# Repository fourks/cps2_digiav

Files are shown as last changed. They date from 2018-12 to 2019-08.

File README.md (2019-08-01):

CPS2 digital AV interface (Rev 2 - CPS1 branch)
==============

Features (current)
--------------------------
* framelocked 1080p@59.64Hz output with max. 40 scanline latency
* 24bit/48kHz audio output

TODO
--------------------------
* OSD/UI
* resolution select
* more scanline options
* settings store / profiles

Installation
--------------------------
The add-on board can be installed on top of CPS1 A-board (88617A revisions currently supported). The following additional parts are required:

* cps1_adapter PCB and related parts, see pcb_cps1_adapter folder
* 3pcs 2x5 U-type pin headers
* ribbon cable
* coaxial cable (~40cm)

Installation instructions are found in pcb/doc/install.md .

Usage
--------------------------
Board is controlled via two external buttons:
* BTN1: change vertical offset (0-8, default=4)
* BTN2: enable/disable scanlines

More info and discussion
--------------------------
* [Forum topic](http://shmups.system11.org/viewtopic.php?f=6&t=59479&p=1266977)

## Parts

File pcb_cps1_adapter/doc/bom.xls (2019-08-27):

Id | Designator | Package | Quantity | Designation | Supplier and ref
1 | U1 | TSSOP-16_4.4x5mm_P0.65mm | 1 | 74LVC112 | https://www.digikey.fi/product-detail/en/texas-instruments/SN74LVC112APWR/296-8450-1-ND/377408
2 | U2 | SSOP-20_5.3x7.2mm_P0.65mm | 1 | WM8782 | https://www.digikey.fi/product-detail/en/cirrus-logic-inc/WM8782SEDS-V/598-2466-ND/5036698
3 | J1,J2,J3 | BCS-105-L-D-PE-BE | 3 | Conn_02x05_Counter_Clockwise | https://www.digikey.fi/products/en?keywords=BCS-105-L-D-PE-BE%20
4 | C2,C4,C7,C6,C11 | SM0603_Capa_libcms | 5 | 0.1u | https://www.digikey.fi/product-detail/en/samsung-electro-mechanics/CL10B104KB8NNNC/1276-1000-1-ND/3889086
5 | C1,C3,C5,C8,C10 | SM0603_Capa_libcms | 5 | 10u | https://www.digikey.fi/product-detail/en/avx-corporation/0603ZD106KAT2A/478-10766-1-ND/7536554
6 | R1 | SM0603_Resistor_libcms | 1 | 1.8k | https://www.digikey.fi/product-detail/en/yageo/RC0603FR-071K8L/311-1.80KHRCT-ND/729821
7 | R2 | SM0603_Resistor_libcms | 1 | 3.3k | https://www.digikey.fi/product-detail/en/yageo/RT0603FRE073K3L/YAG3354CT-ND/5418059
8 | R4 | SM0603_Resistor_libcms | 1 | 1M | https://www.digikey.fi/product-detail/en/yageo/RC0603FR-071ML/311-1.00MHRCT-ND/729791
9 | J4,J5 |  | 1 |  | https://www.digikey.fi/product-detail/en/samtec-inc/TSW-120-07-G-S/SAM1029-20-ND/1101307

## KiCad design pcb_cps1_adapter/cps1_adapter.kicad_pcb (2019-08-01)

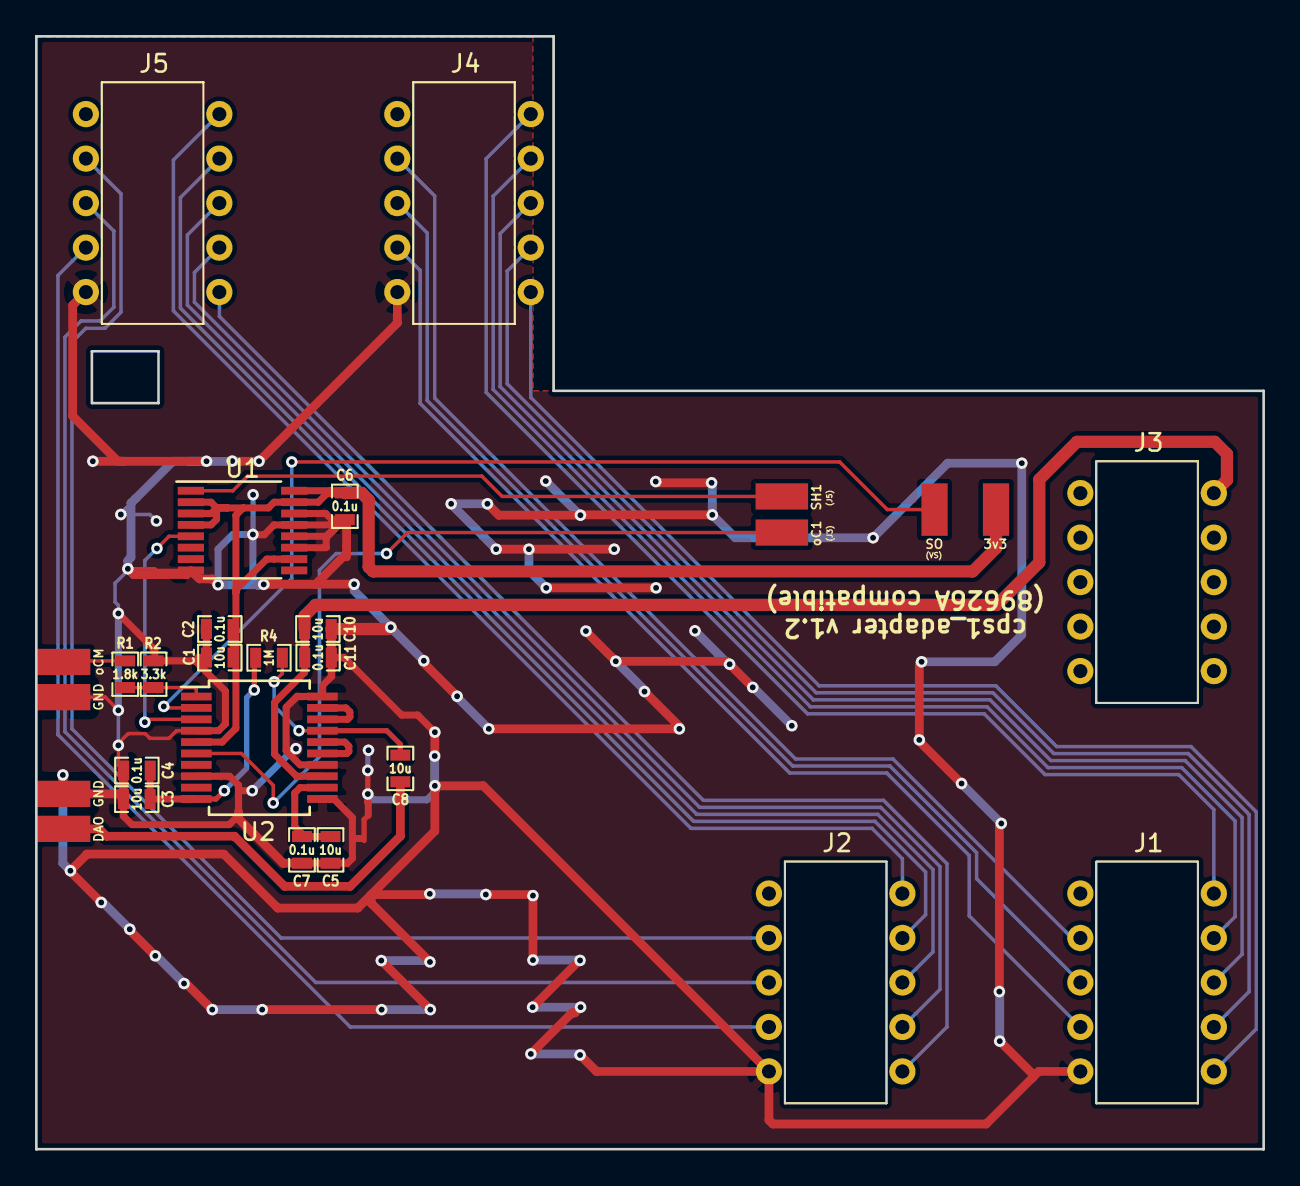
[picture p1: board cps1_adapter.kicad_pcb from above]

Board: 2 copper layers, 70.1 x 63.5 mm, 28 parts (0 on the bottom side), 31 nets.

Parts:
C1, C3, C5, C8, C10: 10u; SM0603_Capa_libcms
C2, C4, C6, C7, C11: 0.1u; SM0603_Capa_libcms
J1, J2, J3, J4, J5: Conn_02x05_Counter_Clockwise; HLE-105-02-G-DV-PE
R1: 1.8k; SM0603_Resistor_libcms
R2: 3.3k; SM0603_Resistor_libcms
R4: 1M; SM0603_Resistor_libcms
TP1, TP8: GND; SMD_PAD
TP2: DAO; SMD_PAD
TP3: 3v3; SMD_PAD
TP4: SO; SMD_PAD
TP6: oC1; SMD_PAD
TP7: SH1; SMD_PAD
TP9: oCM; SMD_PAD
U1: 74LVC112; TSSOP-16_4.4x5mm_P0.65mm
U2: WM8782; SSOP-20_5.3x7.2mm_P0.65mm

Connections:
/B0: J1.2, J4.2
/B1: J1.3, J4.3
/B2: J1.4, J4.4
/B3: J1.6, J4.6
/DAO: C8.1, TP2.1
/DVDD3V3: C1.1, C2.1, C6.1, TP3.1, U1.2, U1.3, U1.4, U1.10, U1.15, U1.16, U2.5
/DVDD5V: C10.1, C11.1, J3.10, U2.13
/F0: J2.7, J5.7
/F1: J2.8, J5.8
/F2: J2.9, J5.9
/F3: J2.10, J5.10
/G0: J1.7, J4.7
/G1: J1.8, J4.8
/G2: J1.9, J4.9
/G3: J1.10, J4.10
/LRCLK: U1.5, U2.3
/R0: J2.2, J5.2
/R1: J2.3, J5.3
/R2: J2.4, J5.4
/R3: J2.6, J5.6
/SH1: TP7.1, U1.1
/SO: TP4.1, U2.2
/VMID: C3.1, C4.1, R4.1, U2.10
/oC1: TP6.1, U2.6
/oCM: R1.1, TP9.1
GND: C1.2, C2.2, C3.2, C4.2, C5.2, C6.2, C7.2, C10.2, C11.2, J1.5, J2.5, J4.5, J5.5, R2.2, TP1.1, TP8.1, U1.8, U1.11, U1.12, U1.13, U1.14, U2.4, U2.8, U2.11, U2.14, U2.20
unnamed: C5.1, C7.1, U2.12
unnamed: C8.2, R4.2, U2.17
unnamed: R1.2, R2.1, U2.1
unnamed: U2.15, U2.16
unnamed: U2.18, U2.19

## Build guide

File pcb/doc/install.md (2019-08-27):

A-board (revision 89626A-4) signal reference
--------------------------
[List of hookup points](./cps1_hookup_points.txt)

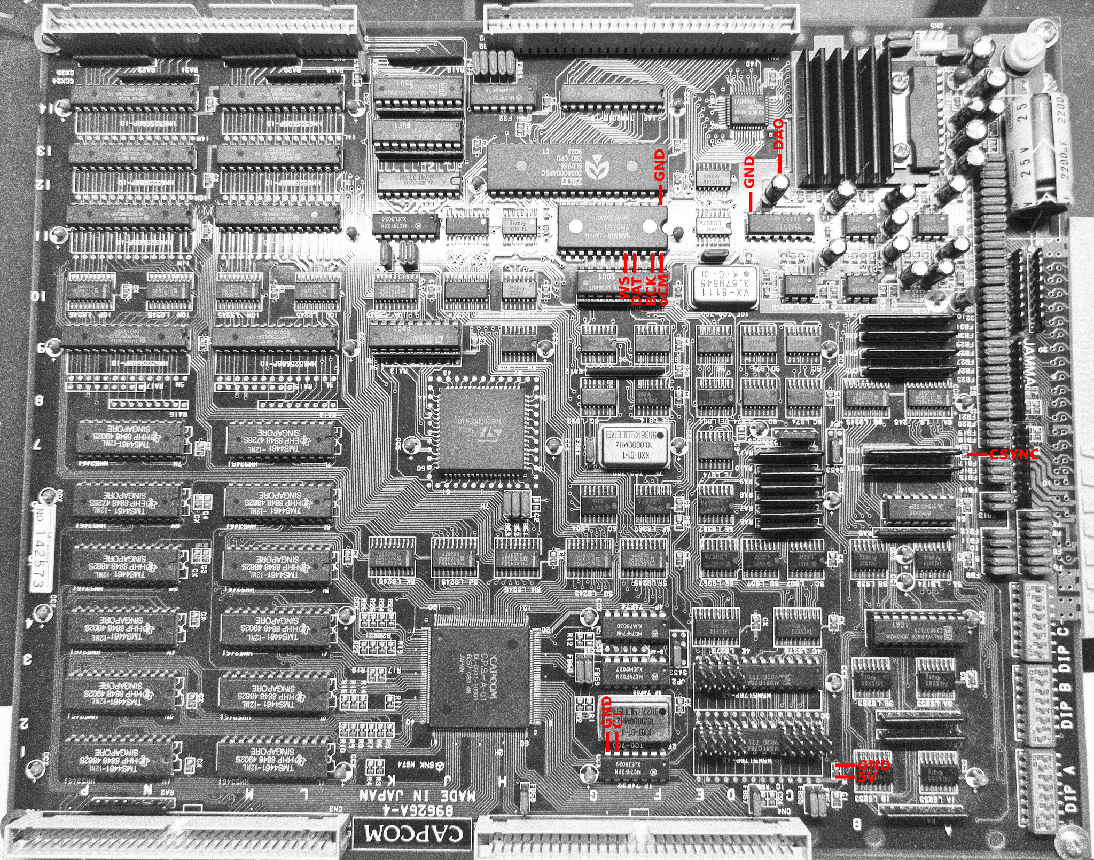
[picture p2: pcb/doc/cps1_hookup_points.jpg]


Step 1: Preparation
--------------------------

Solder 3pcs U-shaped 2x5 headers M5M RAM chips as shown in the image below. Solder BCS-105-L-D-PE-BE sockets on cps1_adapter (J1-3) and trim down pin metals underside the PCB. Make sure the adapter PCB fits in place before going forward. Solder R7+R8 (2x10k 0603 SMD resistors) on bottom of cps2_digiav board. Install cps2_digiav on top of adapter board via 4pcs 5-pin headers **without using spacers**.

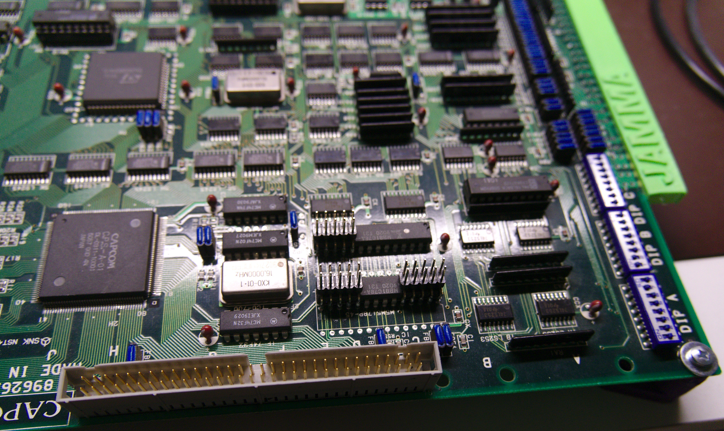
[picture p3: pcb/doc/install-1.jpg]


It is recommened to cover PAL 10A1 IC legs with electrical tape (at least on the side closer to PCB edge) as well as B-board bottom area above JTAG connector (full-length B-boards only). A-board resistor arrays (RA6-8) can be bent a little towards center so that adapter board PCB lies on level above them.

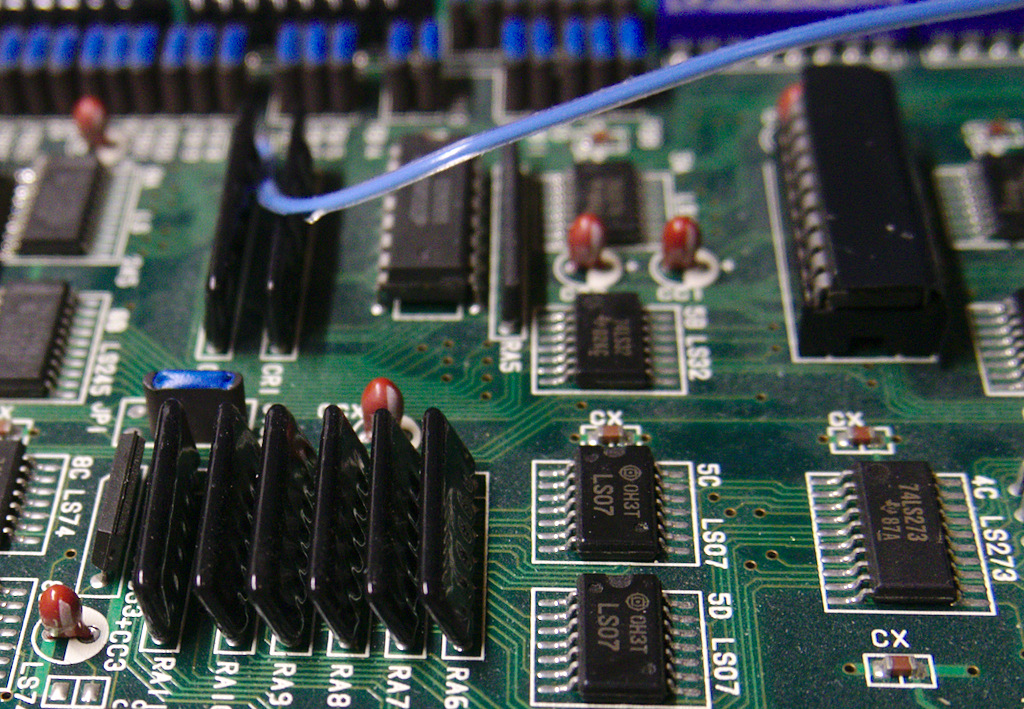
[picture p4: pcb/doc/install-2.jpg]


Step 2: Clock and sync signals
--------------------------

Clock is available on 74F32. It's mandatory to use a coax cable to avoid stability issues caused by noise. Composite sync is extracted from R28 as shown in the signal reference image (connect to HS pin on cps2_digiav).

Step 3: Audio, power and button signals
--------------------------

Audio is extracted from YM2151 and R49. Use coax cable for oCM and DAO signals. 5V/GND can be extracted from certain CCX caps, e.g. the one shown in the signal reference image. Wire two external pushbuttons to the board: one terminal to GND and another to vol-/vol+.

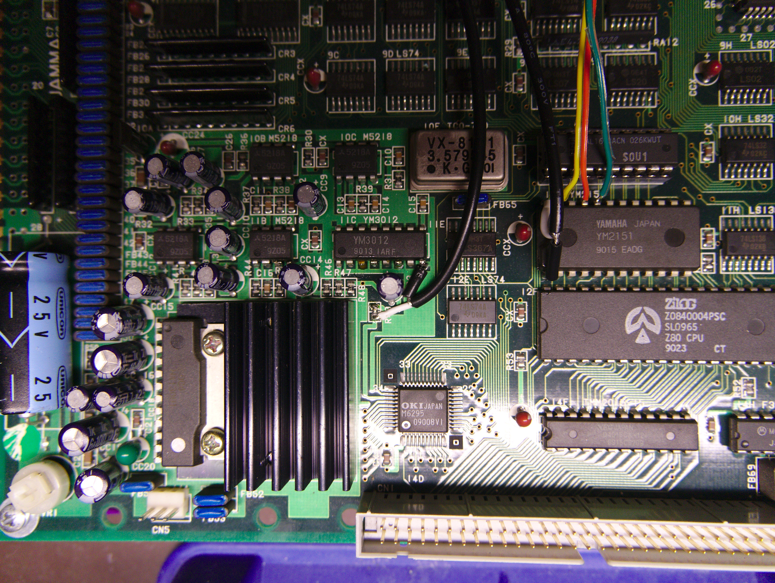
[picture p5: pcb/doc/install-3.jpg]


Step 4: Signals between cps1_adapter and cps2_digiav
--------------------------

Bridge SMD jumpers J3, J5 and J6 on cps2_digiav board. Connect oC1, SH1, SO and 3v3 from cps1_adapter to cps2_digiav as defined in the hookup point list. Add a jumper wire between C1 and C2 pads. (Note that cps2_digiav PCB in picture below is v2.0 which is slightly different)

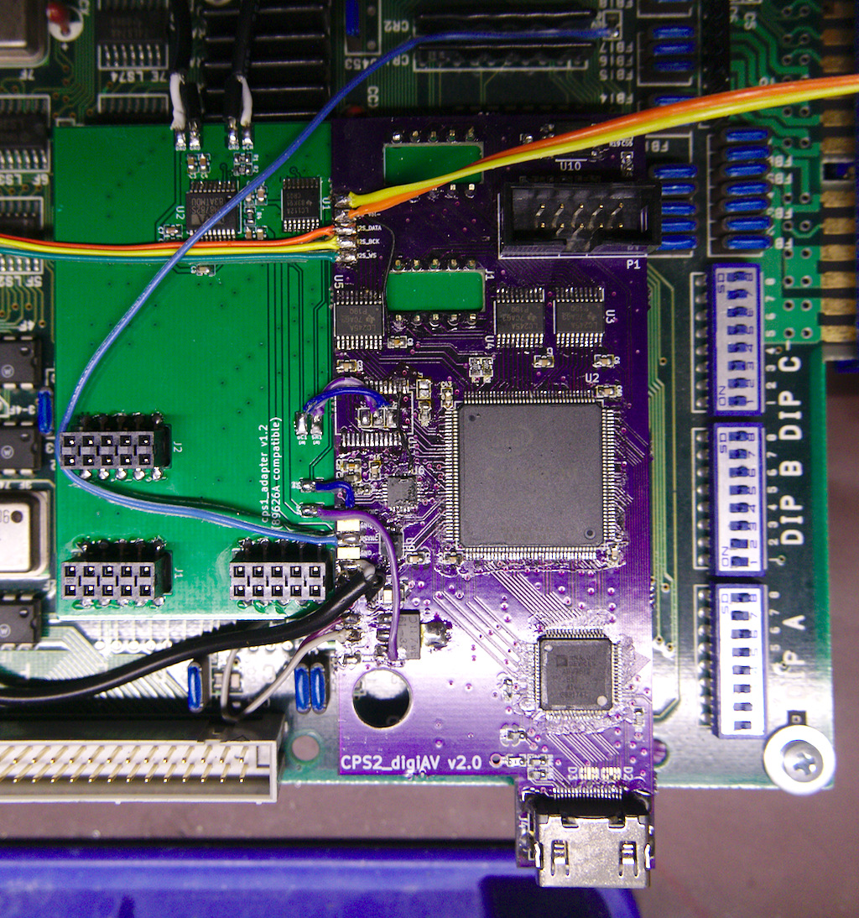
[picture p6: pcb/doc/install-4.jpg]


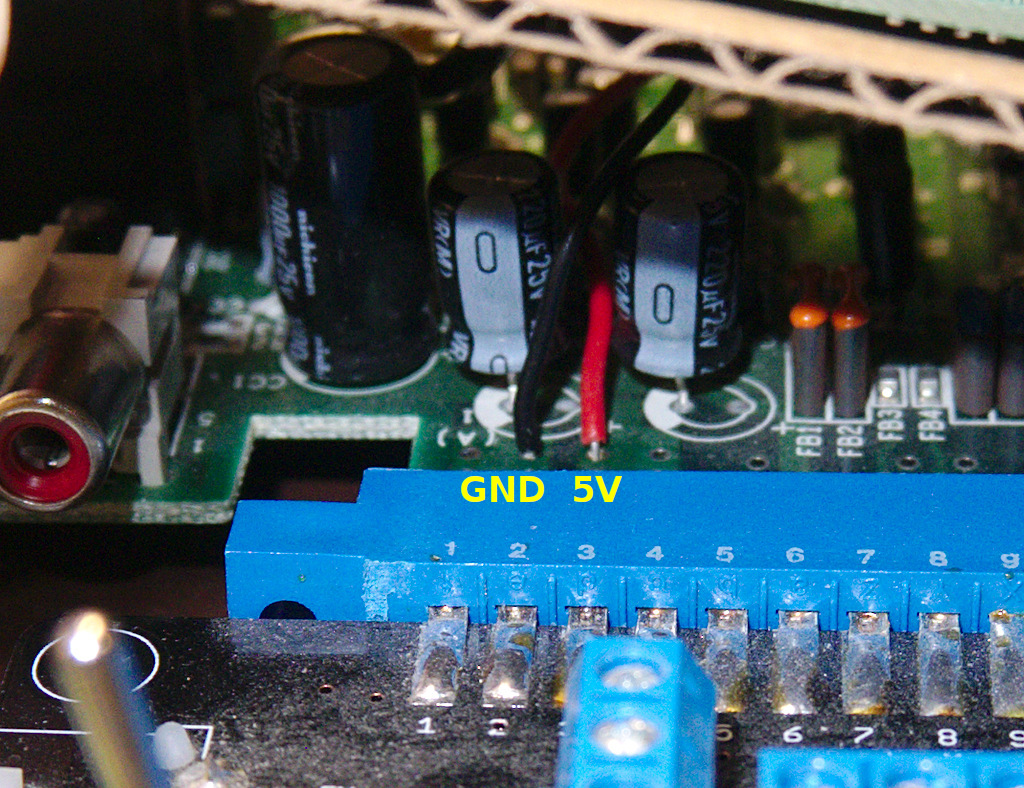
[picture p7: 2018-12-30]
pcb/doc/install-5.jpg

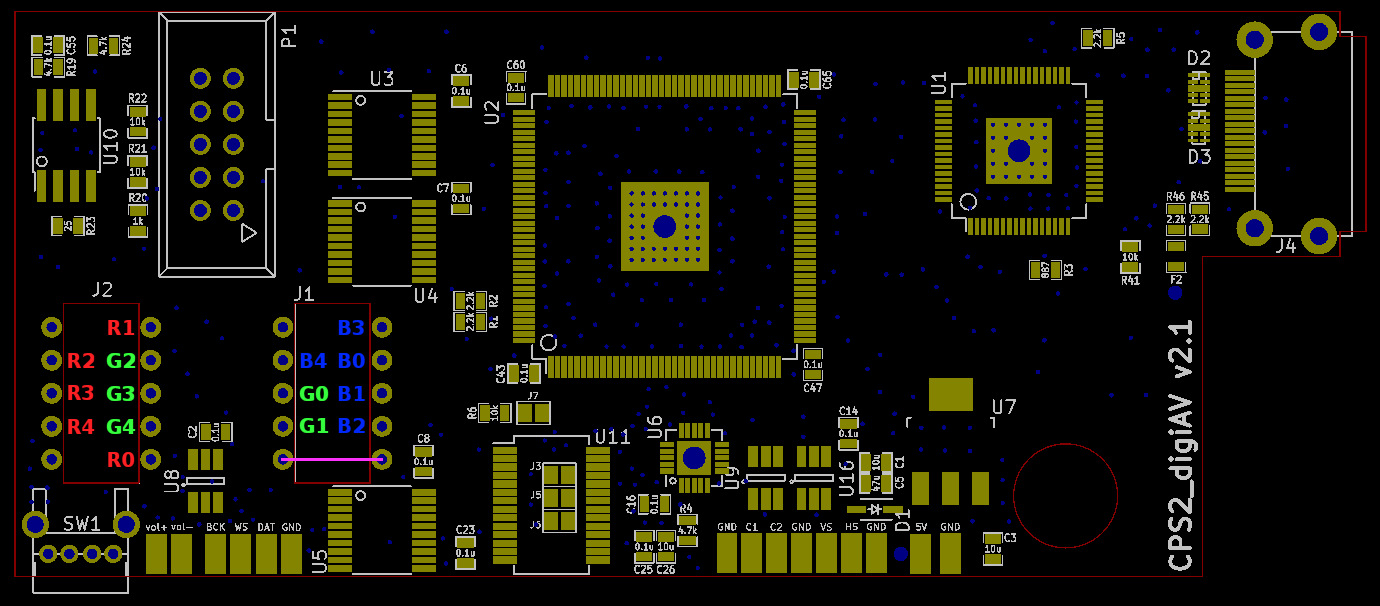
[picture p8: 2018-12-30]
pcb/doc/install-6.jpg

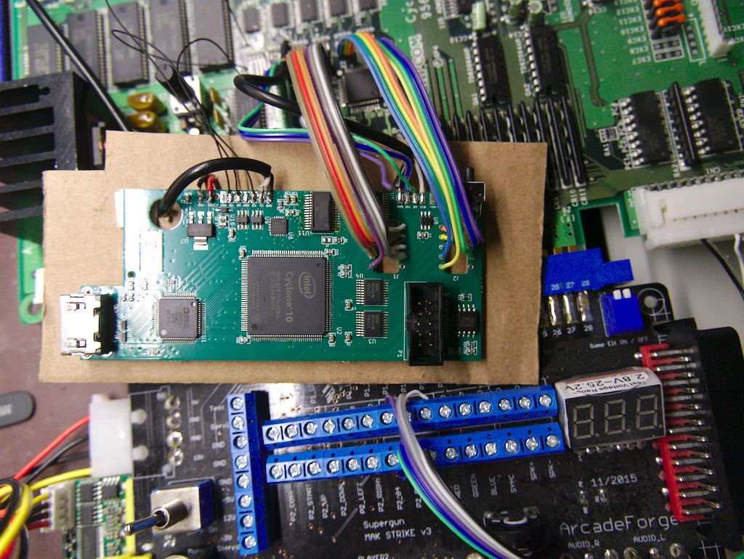
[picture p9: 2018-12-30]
pcb/doc/install-7.jpg

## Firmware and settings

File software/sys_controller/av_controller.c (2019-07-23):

//
// Copyright (C) 2016-2018  Markus Hiienkari <mhiienka@niksula.hut.fi>
//
// This file is part of CPS2 Digital AV Interface project.
//
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

#include <stdio.h>
#include <unistd.h>
#include "system.h"
#include "string.h"
#include "altera_avalon_pio_regs.h"
#include "i2c_opencores.h"
#include "sysconfig.h"

#include "si5351_regs.h"


#define PB_MASK             (3<<30)
#define PB0_BIT             (1<<30)
#define PB1_BIT             (1<<31)

typedef struct {
    const alt_u16 v_initline_ref;
    alt_u8 v_offset;
    alt_u8 v_mult;
    alt_u8 sl_enable;
    alt_u8 sl_str;
    alt_u8 sl_mask;
} mode_config_t;

mode_config_t fpga_480p = {.v_initline_ref=524, .v_offset=0, .v_mult=2, .sl_enable=0, .sl_str=15, .sl_mask=1};
mode_config_t fpga_1080p = {.v_initline_ref=1054, .v_offset=4, .v_mult=5, .sl_enable=0, .sl_str=15, .sl_mask=0x3};

#define ADV7513_BASE (0x72>>1)

inline alt_u32 adv7513_readreg(alt_u8 regaddr)
{
    //Phase 1
    I2C_start(I2CA_BASE, ADV7513_BASE, 0);
    I2C_write(I2CA_BASE, regaddr, 0);

    //Phase 2
    I2C_start(I2CA_BASE, ADV7513_BASE, 1);
    return I2C_read(I2CA_BASE,1);
}

inline void adv7513_writereg(alt_u8 regaddr, alt_u8 data)
{
    I2C_start(I2CA_BASE, ADV7513_BASE, 0);
    I2C_write(I2CA_BASE, regaddr, 0);
    I2C_write(I2CA_BASE, data, 1);
}

inline alt_u32 si5351_readreg(alt_u8 regaddr)
{
    //Phase 1
    I2C_start(I2CA_BASE, SI5351_BASE, 0);
    I2C_write(I2CA_BASE, regaddr, 0);

    //Phase 2
    I2C_start(I2CA_BASE, SI5351_BASE, 1);
    return I2C_read(I2CA_BASE,1);
}

inline void si5351_writereg(alt_u8 regaddr, alt_u8 data)
{
    I2C_start(I2CA_BASE, SI5351_BASE, 0);
    I2C_write(I2CA_BASE, regaddr, 0);
    I2C_write(I2CA_BASE, data, 1);
}


void init_si5351() {
    int i;

    // Wait until Si5351 initialization is complete
    while ((si5351_readreg(0x00) & 0x80) == 0x80) ;

    for (i=0; i<SI5351C_REVB_REG_CONFIG_NUM_REGS; i++)
        si5351_writereg(si5351c_revb_registers[i].address, si5351c_revb_registers[i].value);

    printf("Waiting PLL lock\n");
    while ((si5351_readreg(0x00) & (1<<4)) != 0x00) ;
}

void init_adv() {
    // Wait until display is detected
    while ((adv7513_readreg(0x42) & 0x60) != 0x60) ;

    // Power up TX
    adv7513_writereg(0x41, 0x10);
    //adv7513_writereg(0xd6, 0xc0);

    // Setup fixed registers
    adv7513_writereg(0x98, 0x03);
    adv7513_writereg(0x9A, 0xE0);
    adv7513_writereg(0x9C, 0x30);
    adv7513_writereg(0x9D, 0x01);
    adv7513_writereg(0xA2, 0xA4);
    adv7513_writereg(0xA3, 0xA4);
    adv7513_writereg(0xE0, 0xD0);
    adv7513_writereg(0xF9, 0x00);

    // Setup audio format
    adv7513_writereg(0x12, 0x20); // disable copyright protection
    adv7513_writereg(0x13, 0x20); // set category code
    adv7513_writereg(0x14, 0x0B); // 24-bit audio
    adv7513_writereg(0x15, 0x20); // 48kHz audio Fs, 24-bit RGB

    // Input video format
    adv7513_writereg(0x16, 0x30); // RGB 8bpc
    adv7513_writereg(0x17, 0x02); // 16:9 aspect

    // HDMI output without HDCP
    adv7513_writereg(0xAF, 0x06);

    // No clock delay (?)
    adv7513_writereg(0xBA, 0x60);

    // Audio regeneration settings
    adv7513_writereg(0x01, 0x00);
    adv7513_writereg(0x02, 0x18);
    adv7513_writereg(0x03, 0x00); // N=6144
    //adv7513_writereg(0x0A, 0x00);
    adv7513_writereg(0x0C, 0x04); // I2S0 input

    // Setup InfoFrame
    adv7513_writereg(0x4A, 0xC0); // Enable InfoFrame modify
    adv7513_writereg(0x55, 0x02); // No overscan
    adv7513_writereg(0x57, 0x08); // Full-range RGB
    adv7513_writereg(0x4A, 0x80); // Disable InfoFrame modify
}

// Initialize hardware
int init_hw()
{
    alt_u8 retval;
    I2C_init(I2C_OPENCORES_0_BASE,ALT_CPU_FREQ,400000);

    // reset syncgen etc.
    IOWR_ALTERA_AVALON_PIO_DATA(PIO_3_BASE, 0x0);
    usleep(200000);

    printf("Init Si5351\n");
    init_si5351();

    // deassert syncgen reset
    IOWR_ALTERA_AVALON_PIO_DATA(PIO_3_BASE, (1<<31));

    retval = adv7513_readreg(0x00);

    if ( retval != 0x13) {
        printf("Error: could not read from ADV7513 (0x%x)\n", retval);
        return -1;
    }

    printf("Init ADV7513\n");
    init_adv();

    return 0;
}

void program_mode(mode_config_t *mode_ptr, int resync) {
    alt_u32 x_info;

    IOWR_ALTERA_AVALON_PIO_DATA(PIO_1_BASE, 0);
    IOWR_ALTERA_AVALON_PIO_DATA(PIO_2_BASE, ((mode_ptr->v_initline_ref-(mode_ptr->v_mult*mode_ptr->v_offset))<<4)|mode_ptr->v_offset);
    IOWR_ALTERA_AVALON_PIO_DATA(PIO_3_BASE, (1<<31)|(mode_ptr->sl_mask<<6)|(mode_ptr->sl_str<<2)|mode_ptr->sl_enable);

    if (resync) {
        usleep(20000);
        x_info = IORD_ALTERA_AVALON_PIO_DATA(PIO_3_BASE);
        IOWR_ALTERA_AVALON_PIO_DATA(PIO_3_BASE, (x_info & ~(1<<31)));
        IOWR_ALTERA_AVALON_PIO_DATA(PIO_3_BASE, x_info);
    }
}

int main()
{
    alt_u8 rd;
    alt_u32 btn_vec, btn_vec_prev=0;
    alt_u32 lines;
    alt_u32 ncts;
    mode_config_t *mode_ptr = &fpga_1080p;

    int init_stat;

    init_stat = init_hw();

    if (init_stat >= 0) {
        printf("### cps2_digiAV INIT OK ###\n\n");
    } else {
        printf("Init error  %d", init_stat);
        while (1) {}
    }

    program_mode(mode_ptr, 1);

    while(1) {

        btn_vec = ~IORD_ALTERA_AVALON_PIO_DATA(PIO_0_BASE) & PB_MASK;

        if ((btn_vec_prev == 0) && btn_vec) {
            if (btn_vec & PB0_BIT) {
                mode_ptr->sl_enable ^= 1;
                program_mode(mode_ptr, 0);
            }
            if (btn_vec & PB1_BIT) {
                mode_ptr->v_offset = (mode_ptr->v_offset + 1) % 9;
                program_mode(mode_ptr, 1);
            }
        }

        if (!(adv7513_readreg(0x42) & 0x20)) {
            printf("Re-init ADV7513\n");
            init_adv();
        }

#ifdef DEBUG
        static int loop_ctr = 0;
        ncts = 0;
        ncts |= (adv7513_readreg(0x04) & 0xf) << 16;
        ncts |= adv7513_readreg(0x05) << 8;
        ncts |= adv7513_readreg(0x06);
        rd = !!(adv7513_readreg(0x9e) & (1<<4));

        if ((loop_ctr++ % 100) == 0) {
            printf("NCTS: %lu\n", ncts);
            printf("btnvec: 0x%lx\n", btn_vec>>30);
            printf("PLL lock: %u\n", rd);
        }
#endif
        btn_vec_prev = btn_vec;

        usleep(WAITLOOP_SLEEP_US);
    }

    return 0;
}

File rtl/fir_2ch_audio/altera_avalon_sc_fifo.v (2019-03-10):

// -----------------------------------------------------------
// Legal Notice: (C)2007 Altera Corporation. All rights reserved.  Your
// use of Altera Corporation's design tools, logic functions and other
// software and tools, and its AMPP partner logic functions, and any
// output files any of the foregoing (including device programming or
// simulation files), and any associated documentation or information are
// expressly subject to the terms and conditions of the Altera Program
// License Subscription Agreement or other applicable license agreement,
// including, without limitation, that your use is for the sole purpose
// of programming logic devices manufactured by Altera and sold by Altera
// or its authorized distributors.  Please refer to the applicable
// agreement for further details.
//
// Description: Single clock Avalon-ST FIFO.
// -----------------------------------------------------------

`timescale 1 ns / 1 ns


//altera message_off 10036
module altera_avalon_sc_fifo
#(
    // --------------------------------------------------
    // Parameters
    // --------------------------------------------------
    parameter SYMBOLS_PER_BEAT  = 1,
    parameter BITS_PER_SYMBOL   = 8,
    parameter FIFO_DEPTH        = 16,
    parameter CHANNEL_WIDTH     = 0,
    parameter ERROR_WIDTH       = 0,
    parameter USE_PACKETS       = 0,
    parameter USE_FILL_LEVEL    = 0,
    parameter USE_STORE_FORWARD = 0,
    parameter USE_ALMOST_FULL_IF = 0,
    parameter USE_ALMOST_EMPTY_IF = 0,

    // --------------------------------------------------
    // Empty latency is defined as the number of cycles
    // required for a write to deassert the empty flag.
    // For example, a latency of 1 means that the empty
    // flag is deasserted on the cycle after a write.
    //
    // Another way to think of it is the latency for a
    // write to propagate to the output. 
    // 
    // An empty latency of 0 implies lookahead, which is
    // only implemented for the register-based FIFO.
    // --------------------------------------------------
    parameter EMPTY_LATENCY     = 3,
    parameter USE_MEMORY_BLOCKS = 1,

    // --------------------------------------------------
    // Internal Parameters
    // --------------------------------------------------
    parameter DATA_WIDTH  = SYMBOLS_PER_BEAT * BITS_PER_SYMBOL,
    parameter EMPTY_WIDTH = log2ceil(SYMBOLS_PER_BEAT)
)
(
    // --------------------------------------------------
    // Ports
    // --------------------------------------------------
    input                       clk,
    input                       reset,

    input [DATA_WIDTH-1: 0]     in_data,
    input                       in_valid,
    input                       in_startofpacket,
    input                       in_endofpacket,
    input [((EMPTY_WIDTH>0) ? (EMPTY_WIDTH-1):0) : 0]     in_empty,
    input [((ERROR_WIDTH>0) ? (ERROR_WIDTH-1):0) : 0]     in_error,
    input [((CHANNEL_WIDTH>0) ? (CHANNEL_WIDTH-1):0): 0]  in_channel,
    output                      in_ready,

    output [DATA_WIDTH-1 : 0]   out_data,
    output reg                  out_valid,
    output                      out_startofpacket,
    output                      out_endofpacket,
    output [((EMPTY_WIDTH>0) ? (EMPTY_WIDTH-1):0) : 0]    out_empty,
    output [((ERROR_WIDTH>0) ? (ERROR_WIDTH-1):0) : 0]    out_error,
    output [((CHANNEL_WIDTH>0) ? (CHANNEL_WIDTH-1):0): 0] out_channel,
    input                       out_ready,

    input [(USE_STORE_FORWARD ? 2 : 1) : 0]   csr_address,
    input                       csr_write,
    input                       csr_read,
    input [31 : 0]              csr_writedata,
    output reg [31 : 0]         csr_readdata,

    output  wire                almost_full_data,
    output  wire                almost_empty_data
);

    // --------------------------------------------------
    // Local Parameters
    // --------------------------------------------------
    localparam ADDR_WIDTH   = log2ceil(FIFO_DEPTH);
    localparam DEPTH        = FIFO_DEPTH;
    localparam PKT_SIGNALS_WIDTH = 2 + EMPTY_WIDTH;
    localparam PAYLOAD_WIDTH     = (USE_PACKETS == 1) ? 
                   2 + EMPTY_WIDTH + DATA_WIDTH + ERROR_WIDTH + CHANNEL_WIDTH:
                   DATA_WIDTH + ERROR_WIDTH + CHANNEL_WIDTH;

    // --------------------------------------------------
    // Internal Signals
    // --------------------------------------------------
    genvar i;

    reg [PAYLOAD_WIDTH-1 : 0] mem [DEPTH-1 : 0];
    reg [ADDR_WIDTH-1 : 0]  wr_ptr;
    reg [ADDR_WIDTH-1 : 0]  rd_ptr;
    reg [DEPTH-1      : 0]  mem_used;

    wire [ADDR_WIDTH-1 : 0] next_wr_ptr;
    wire [ADDR_WIDTH-1 : 0] next_rd_ptr;
    wire [ADDR_WIDTH-1 : 0] incremented_wr_ptr;
    wire [ADDR_WIDTH-1 : 0] incremented_rd_ptr;

    wire [ADDR_WIDTH-1 : 0] mem_rd_ptr;

    wire read;
    wire write;

    reg empty;
    reg next_empty;
    reg full;
    reg next_full;

    wire [PKT_SIGNALS_WIDTH-1 : 0] in_packet_signals;
    wire [PKT_SIGNALS_WIDTH-1 : 0] out_packet_signals;
    wire [PAYLOAD_WIDTH-1 : 0] in_payload;
    reg  [PAYLOAD_WIDTH-1 : 0] internal_out_payload;
    reg  [PAYLOAD_WIDTH-1 : 0] out_payload;

    reg  internal_out_valid;
    wire internal_out_ready;

    reg  [ADDR_WIDTH : 0] fifo_fill_level;
    reg  [ADDR_WIDTH : 0] fill_level;

    reg  [ADDR_WIDTH-1 : 0]   sop_ptr = 0;
    wire [ADDR_WIDTH-1 : 0]   curr_sop_ptr;
    reg  [23:0]   almost_full_threshold;
    reg  [23:0]   almost_empty_threshold;
    reg  [23:0]   cut_through_threshold;
    reg  [15:0]   pkt_cnt;
    reg           drop_on_error_en;
    reg           error_in_pkt;
    reg           pkt_has_started;
    reg           sop_has_left_fifo;
    reg           fifo_too_small_r;
    reg           pkt_cnt_eq_zero;
    reg           pkt_cnt_eq_one;

    wire          wait_for_threshold;
    reg           pkt_mode;
    wire          wait_for_pkt;
    wire          ok_to_forward;
    wire          in_pkt_eop_arrive;
    wire          out_pkt_leave;
    wire          in_pkt_start;
    wire          in_pkt_error;
    wire          drop_on_error;
    wire          fifo_too_small;
    wire          out_pkt_sop_leave;
    wire [31:0]   max_fifo_size;
    reg           fifo_fill_level_lt_cut_through_threshold;
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

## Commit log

2018-12-28 remove pcb files from cps3 branch
    [bom.xls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]
2019-03-10 port audio ASRC implementation from main branch
    [fir_2ch_audio_param.txt]
2019-06-08 add cps1 branch
    [bom.xls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]
2019-07-23 fix random startup problem
    [av_controller.c]
2019-07-23 update adapter board to version 1.1
    [bom.xls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]
2019-08-01 update cps1_adapter to version 1.2
    [cps1_adapter-B_Cu.gbr, cps1_adapter-B_Mask.gbr, cps1_adapter-B_Paste.gbr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]
2019-08-27 update BOM and instructions
    [bom.xls]
2019-09-26 remove pcb files from cps1 branch
    [bom.xls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]

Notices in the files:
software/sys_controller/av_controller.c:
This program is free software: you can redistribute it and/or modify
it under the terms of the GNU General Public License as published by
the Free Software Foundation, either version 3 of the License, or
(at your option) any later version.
